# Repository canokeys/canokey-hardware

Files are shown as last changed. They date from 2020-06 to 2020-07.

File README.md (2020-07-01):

# CanoKey Hardware Design

This repository contains schematics, PCB projects, and Gerber files of Canokeys.

## Hardware Variants

- `CanoKey NFC-A`: The Canokey with on-board USB Type-A connector and NFC antenna.
- `CanoKey NFC-C`: The Canokey with USB Type-C connector and NFC antenna.
- `CanoKey Nano-A`: The small-sized Canokey which fits inside USB Type-A port.

## License

All hardware, unless otherwise noted, is dual-licensed under CERN and CC-BY-SA. You may use CanoKey hardware under the terms of either the CERN 1.2 license or CC-BY-SA 4.0 license.

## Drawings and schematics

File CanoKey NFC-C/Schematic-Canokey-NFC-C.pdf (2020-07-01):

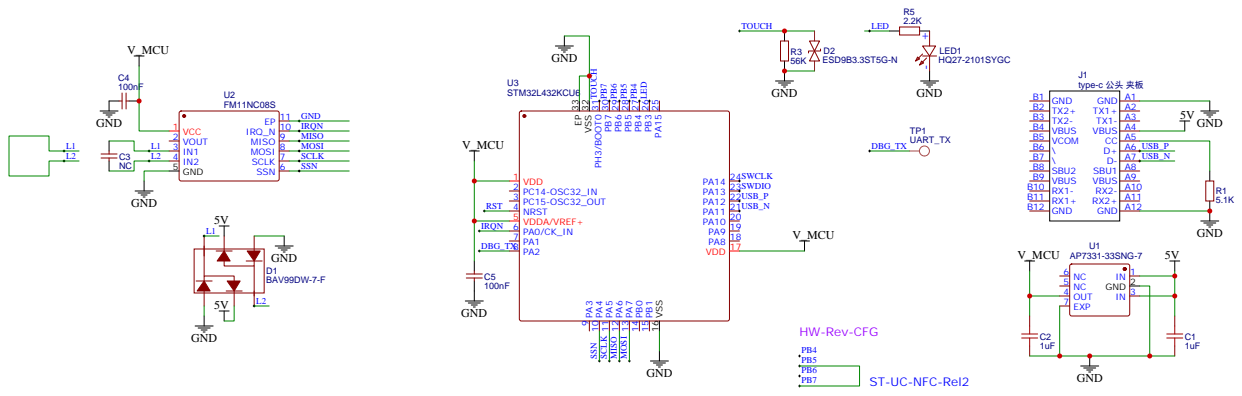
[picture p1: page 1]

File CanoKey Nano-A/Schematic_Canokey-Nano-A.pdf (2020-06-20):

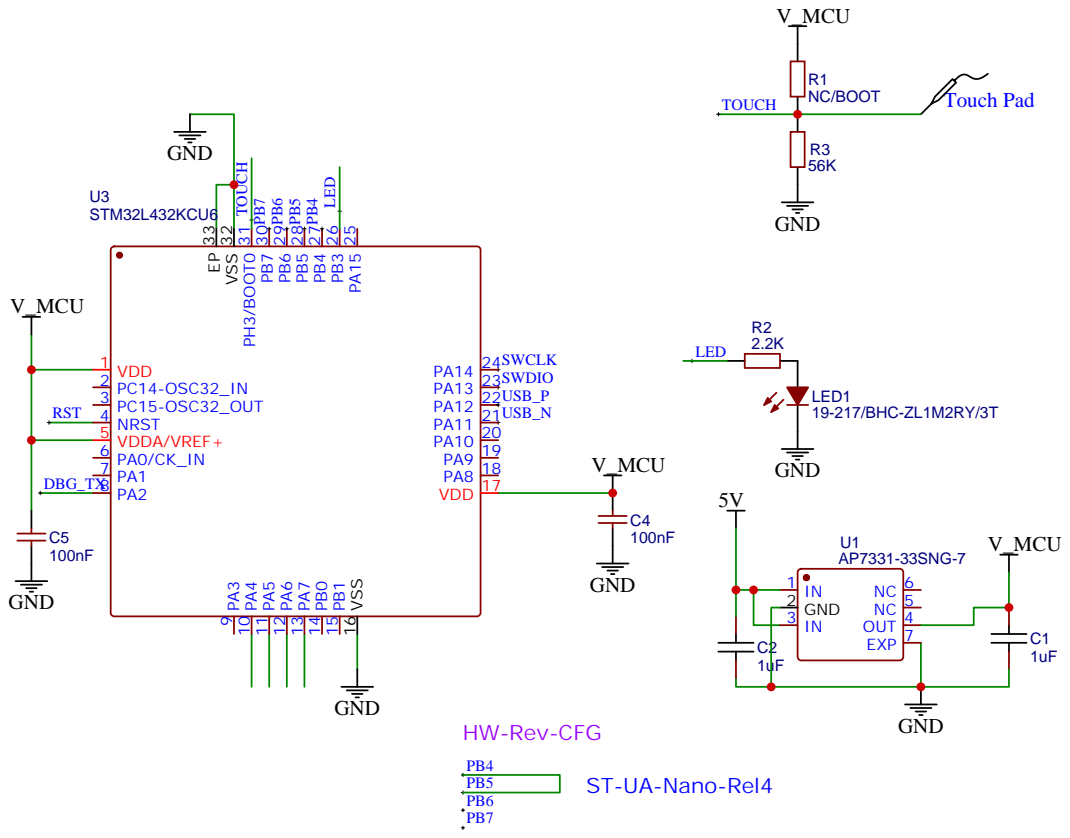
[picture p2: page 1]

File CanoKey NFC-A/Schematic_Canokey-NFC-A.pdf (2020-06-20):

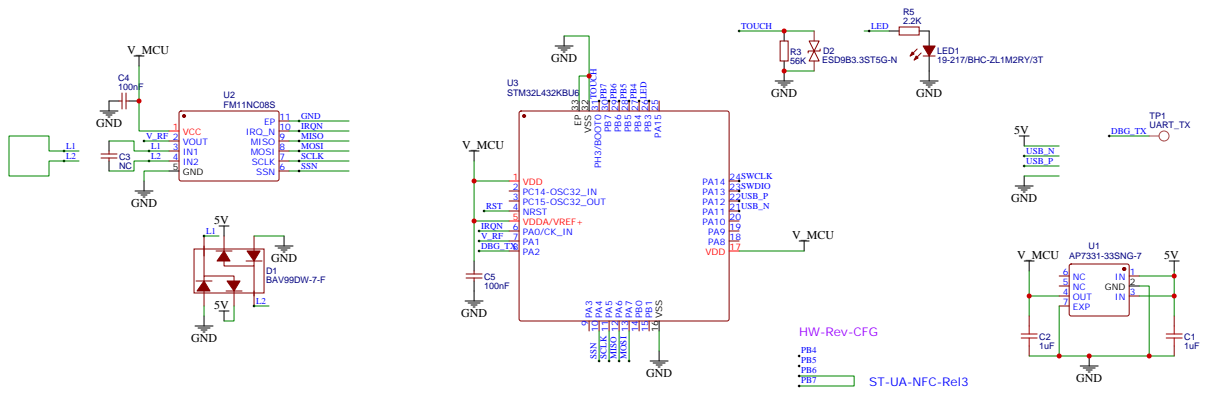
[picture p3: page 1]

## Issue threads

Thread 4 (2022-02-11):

esd protection is missing on usb

lllaaa, 2022-02-11:

z4yx, 2022-02-17:
STM32 features built-in ESD protection.
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

z4yx, 2022-02-18:
When you touch the key while it's plugged, a severe static discharge from the human body to the ground can happen. So we add an extra diode to enhance the protection level.

Closed 2024-07-04.

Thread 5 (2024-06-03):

CanoKey Nano-A PCB thickness and housing size

Lillythefox, 2024-06-03:
Hello,

Im just wondering what PCB thickness you used for the Nano-A? Also dose it need a metal housing like the Nitrokey 3A Mini?
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
See how the PCB is in the metal housing so the components are not damaged.

z4yx, 2024-07-04:
The thickness of the PCB with housing should be 2.5mm. We don't have the housing design yet. A piece of paper sticked on PCB can be used for prototyping.

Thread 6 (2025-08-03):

关于NFC和低功耗

rayc345, 2025-08-03:
1. 想问下NFC的方案里，为什么NFC芯片的VOUT没有被用起来？目前设计是通过桥式整流得到直流电压，经过LDO供电给MCU。为什么不用NFC芯片自带的电压输出？桥式整流会带来约1V的电压损耗。
2. MCU支持1.8V供电，如果配置NFC芯片输出1.8V供电给MCU，可以大幅度改善NFC的灵敏度。为什么没有这么设计呢？是有特殊考虑吗？

z4yx, 2025-08-08:
早期我们尝试过用NFC芯片自带的稳压输出给MCU供电。但是发现MCU峰值功耗超出NFC芯片供电能力，导致NFC芯片进入异常状态，无法完成寻卡动作。所以才设计了独立供电电路给MCU功能。

z4yx, 2025-08-09:
不错，新型号可能功耗更小。期待你的实验成功。

dangfan, 2025-08-09:
可以尝试用FM11NT系列，NFC输出功率会大一些

rayc345, 2025-08-11:
NFC芯片这边可能会有难度，初步看了下芯片资料公开的都很少，估计要NDA，不太好弄。先还用开源方案的吧，硬件软件都有配套的。

dangfan, 2025-08-11:
11NT代码我们也开源了

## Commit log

2020-06-10 add hardware design files
    [Gerber_BoardOutline.GKO, Gerber_BottomLayer.GBL, Gerber_BottomPasteMaskLayer.GBP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]
2020-06-20 add Nano-A
    [Gerber_BoardOutline.GKO, Gerber_BottomLayer.GBL, Gerber_BottomSilkLayer.GBO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]
2020-06-26 CanoKey Nano-A: Sync PCB capacitor value from schematic
2020-07-01 add NFC-C
    [Gerber_BoardOutline.GKO, Gerber_BottomLayer.GBL, Gerber_BottomPasteMaskLayer.GBP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]
2022-03-25 update PCB project
    [Drill_NPTH_Through.DRL, Drill_PTH_Through.DRL, Gerber_BoardOutline.GKO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]
